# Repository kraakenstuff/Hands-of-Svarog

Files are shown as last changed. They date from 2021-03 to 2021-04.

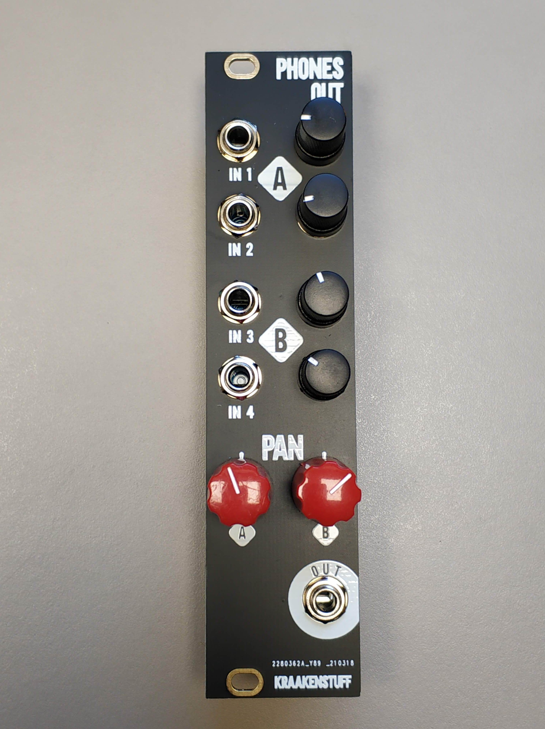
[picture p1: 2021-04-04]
Artwork/Hands-of-Svarog.jpg

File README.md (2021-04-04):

# Hands of Svarog
 A 6HP Eurorack panning mixer and phones output. 
 
 It is inspired by Synthrotek's MST Stereo Output Mixer (https://store.synthrotek.com/MST_Stereo_Output_Mixer). The schematic is based on J3RK's schematic found here: https://www.muffwiggler.com/forum/viewtopic.php?t=224595. I've included a couple of inputs more, swapped his OPA2604 for NJM2068 (because that's what I had) and changed his 33k resistors in output stage for 12k (experiment with those resistors and find a pair that suits your headphones).
 
 As for the functionality, you set levels for your 4 inputs. Then you can pan group A (inputs 1 and 2) and group B (inputs 3 and 4)
 
Note: I wanted panel for this module to include a mixture of Slavic mythology and heavy metal (yeah, why not). But after I made the panel, friends suggested that some symbols ("kolovrat" - a wheel looking one) look like nazi symbols, so I made the (official) panel that is clean and acceptable for all (panel1.png). However, I included the original design here as well (panel.png), without making panel files (in case you find it cool, non-offensive and you make panels for yourself).

Finished module

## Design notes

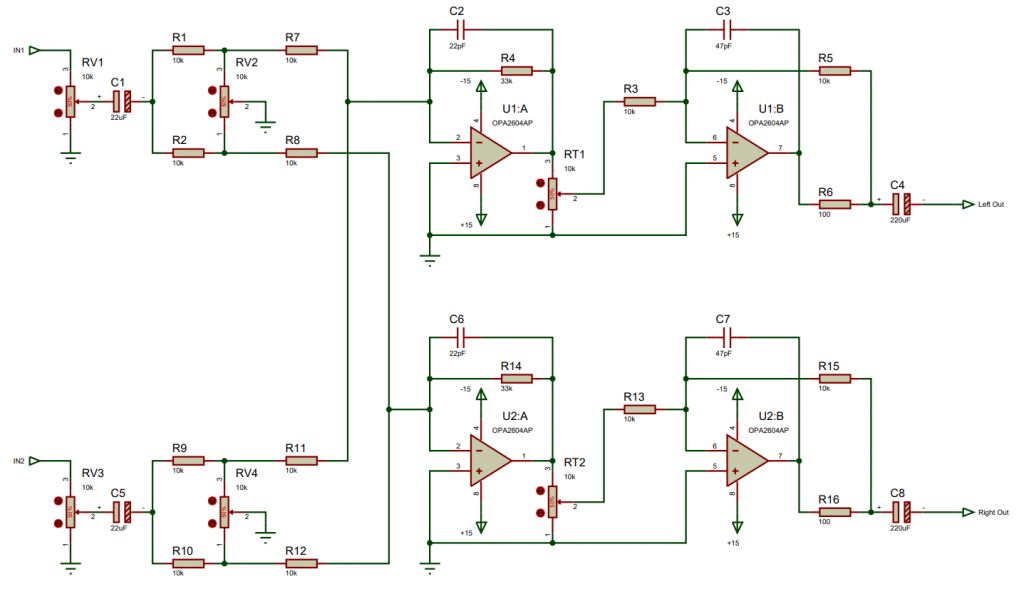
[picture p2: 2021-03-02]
1931_smix_1.jpg

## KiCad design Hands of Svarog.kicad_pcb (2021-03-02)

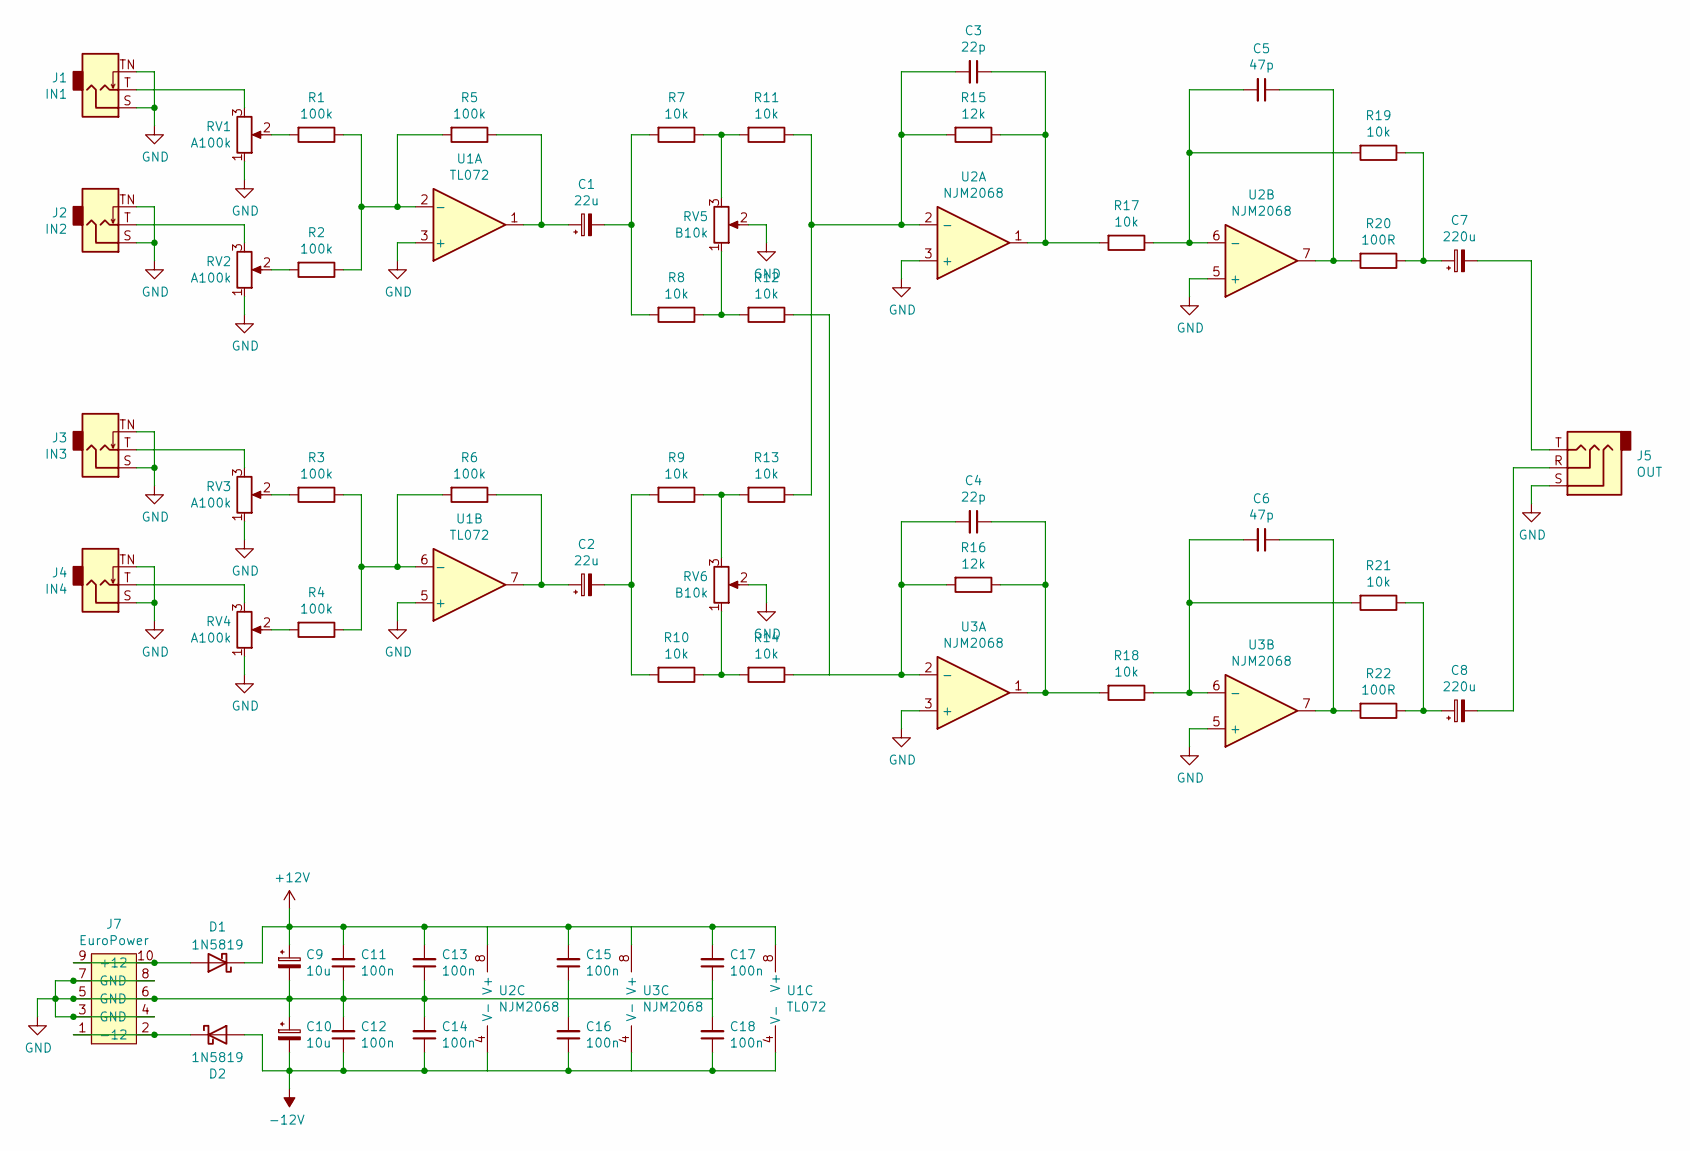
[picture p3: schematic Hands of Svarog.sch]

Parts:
C1, C2: 22u; CP_Elec_5x5.9
C3, C4: 22p; C_0603_1608Metric_Pad1.05x0.95mm_HandSolder
C5, C6: 47p; C_0603_1608Metric_Pad1.05x0.95mm_HandSolder
C7, C8: 220u; CP_Elec_8x10
C9, C10: 10u; CP_Elec_5x5.9
C11, C12, C13, C14, C15, C16, C17, C18: 100n; C_0603_1608Metric_Pad1.05x0.95mm_HandSolder
D1, D2: 1N5819; D_SOD-123
J1: IN1; PJ301M-12-NoHole
J2: IN2; PJ301M-12-NoHole
J3: IN3; PJ301M-12-NoHole
J4: IN4; PJ301M-12-NoHole
J5: OUT; PJ366ST
J7: EuroPower; EuroHeader10
R1, R2, R3, R4, R5, R6: 100k; R_0603_1608Metric_Pad0.98x0.95mm_HandSolder
R7, R8, R9, R10, R11, R12, R13, R14, R17, R18, R19, R21: 10k; R_0603_1608Metric_Pad0.98x0.95mm_HandSolder
R15, R16: 12k; R_0603_1608Metric_Pad0.98x0.95mm_HandSolder
R20, R22: 100R; R_0603_1608Metric_Pad0.98x0.95mm_HandSolder
RV1, RV2, RV3, RV4: A100k; POT-9MM-ALPHA
RV5, RV6: B10k; POT-9MM-ALPHA
U1: TL072; SOIC-8_5.23x5.23mm_P1.27mm
U2, U3: NJM2068; SOIC-8_5.23x5.23mm_P1.27mm

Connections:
+12V: C9.1, C11.2, C13.2, C15.2, C17.2, D1.1 (K), U1.8 (V+), U2.8 (V+), U3.8 (V+)
-12V: C10.2, C12.1, C14.1, C16.1, C18.1, D2.2 (A), U1.4 (V-), U2.4 (V-), U3.4 (V-)
GND: C9.2, C10.1, C11.1, C12.2, C13.1, C14.2, C15.1, C16.2, C17.1, C18.2, J1.S, J1.TN, J2.S, J2.TN, J3.S, J3.TN, J4.S, J4.TN, J5.S, J7.3 (GND), J7.4, J7.5 (GND), J7.6, J7.7 (GND), J7.8, RV1.1, RV2.1, RV3.1, RV4.1, RV5.2, RV6.2, U1.3 (+), U1.5 (+), U2.3 (+), U2.5 (+), U3.3 (+), U3.5 (+)
unnamed: C1.1, R5.1, U1.1
unnamed: C1.2, R7.2, R8.2
unnamed: C2.1, R6.1, U1.7
unnamed: C2.2, R9.2, R10.2
unnamed: C3.1, R15.1, R17.2, U2.1
unnamed: C3.2, R11.1, R13.1, R15.2, U2.2 (-)
unnamed: C4.1, R16.1, R18.2, U3.1
unnamed: C4.2, R12.1, R14.1, R16.2, U3.2 (-)
unnamed: C5.1, R20.2, U2.7
unnamed: C5.2, R17.1, R19.2, U2.6 (-)
unnamed: C6.1, R22.2, U3.7
unnamed: C6.2, R18.1, R21.2, U3.6 (-)
unnamed: C7.1, R19.1, R20.1
unnamed: C7.2, J5.T
unnamed: C8.1, R21.1, R22.1
unnamed: C8.2, J5.R
unnamed: D1.2 (A), J7.9 (+12), J7.10
unnamed: D2.1 (K), J7.1 (-12), J7.2
unnamed: J1.T, RV1.3
unnamed: J2.T, RV2.3
unnamed: J3.T, RV3.3
unnamed: J4.T, RV4.3
unnamed: R1.1, R2.1, R5.2, U1.2 (-)
unnamed: R1.2, RV1.2
unnamed: R2.2, RV2.2
unnamed: R3.1, R4.1, R6.2, U1.6 (-)
unnamed: R3.2, RV3.2
unnamed: R4.2, RV4.2
unnamed: R10.1, R14.2, RV6.1
unnamed: R7.1, R11.2, RV5.3
unnamed: R8.1, R12.2, RV5.1
unnamed: R9.1, R13.2, RV6.3

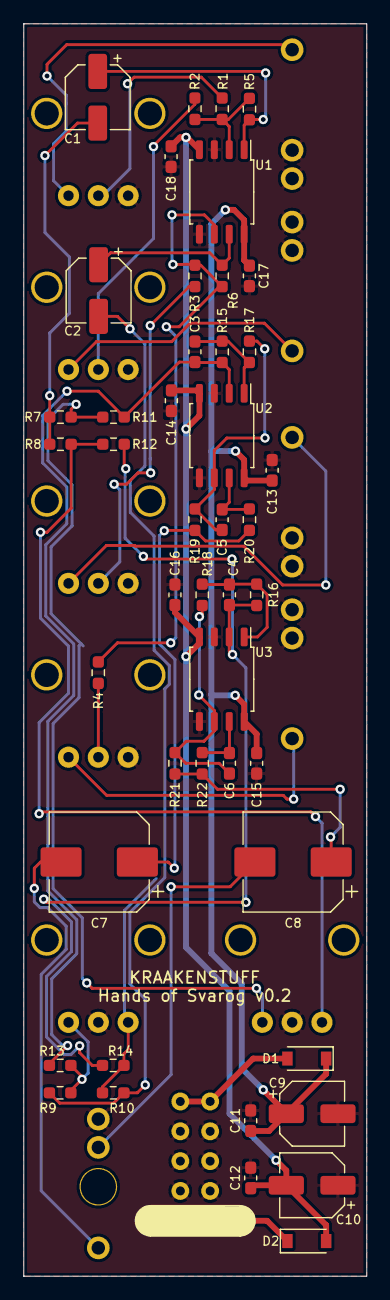
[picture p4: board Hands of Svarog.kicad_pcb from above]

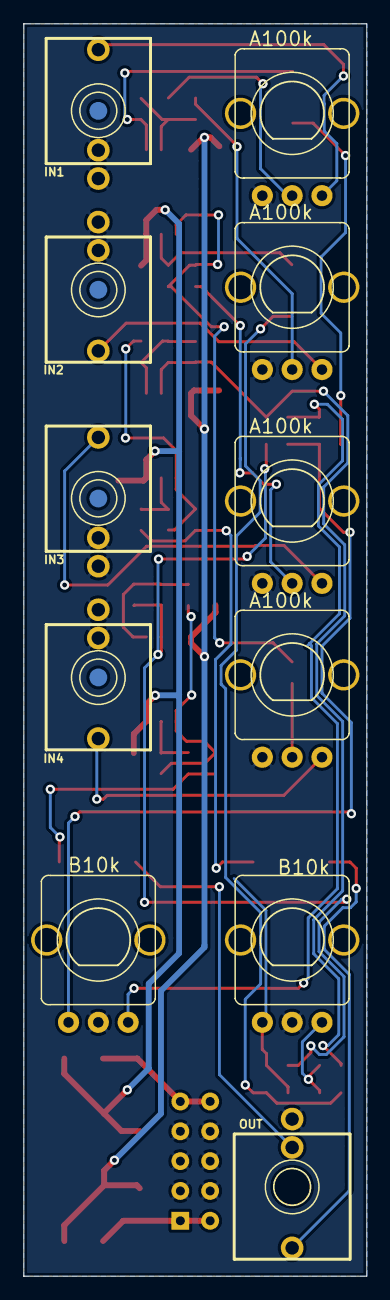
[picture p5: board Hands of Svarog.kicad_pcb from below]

Board: 2 copper layers, 29.2 x 106.7 mm, 57 parts (11 on the bottom side), 35 nets.

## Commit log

2021-03-02 Added v0.2 files
    [Hands of Svarog - panel.kicad_pcb, Hands of Svarog.kicad_pcb, Hands of Svarog.sch]
2021-03-03 Added gerber files
    [Hands_of_Svarog-B_Cu.gbr, Hands_of_Svarog-B_Mask.gbr, Hands_of_Svarog-B_Paste.gbr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]
2021-03-17 Added panel design
    [Hands of Svarog - panel-B_Cu.gbr, Hands of Svarog - panel-B_Mask.gbr, Hands of Svarog - panel-B_Paste.gbr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]
2021-03-29 Fixed panel layout around panning knobs
    [Hands of Svarog - panel.kicad_pcb]
2021-03-29 Updated panel gerbers
    [Hands of Svarog - panel-B_Cu.gbr, Hands of Svarog - panel-B_Mask.gbr, Hands of Svarog - panel-B_Paste.gbr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]
